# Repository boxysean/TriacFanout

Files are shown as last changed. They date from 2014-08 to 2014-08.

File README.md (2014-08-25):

Triac Fanout board for daisy-chainable 8x triac (lightbulb) outputs and Arduino library. So far tested for 8 channels.

[Video](http://instagram.com/p/sIGZ_VrQKr/?modal=true)

Written by Sean McIntyre.
MIT license, all text above must be included in any redistribution

Place the TriacFanout library folder in your <arduinosketchfolder>/libraries/ folder. You may need to create the libraries subfolder if its your first library. Restart the IDE

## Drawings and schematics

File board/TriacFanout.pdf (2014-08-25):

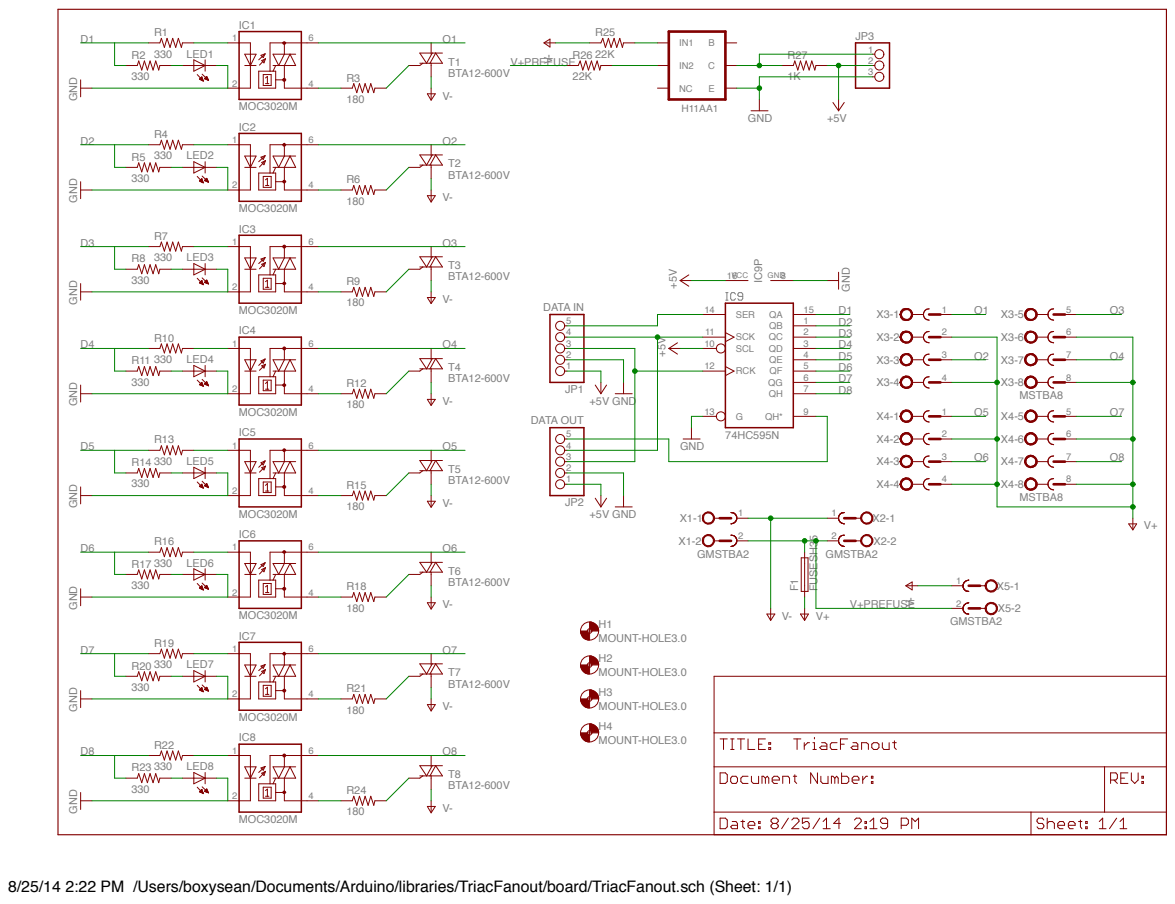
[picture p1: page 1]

8/25/14 2:22 PM /Users/boxysean/Documents/Arduino/libraries/TriacFanout/board/TriacFanout.sch (Sheet: 1/1)

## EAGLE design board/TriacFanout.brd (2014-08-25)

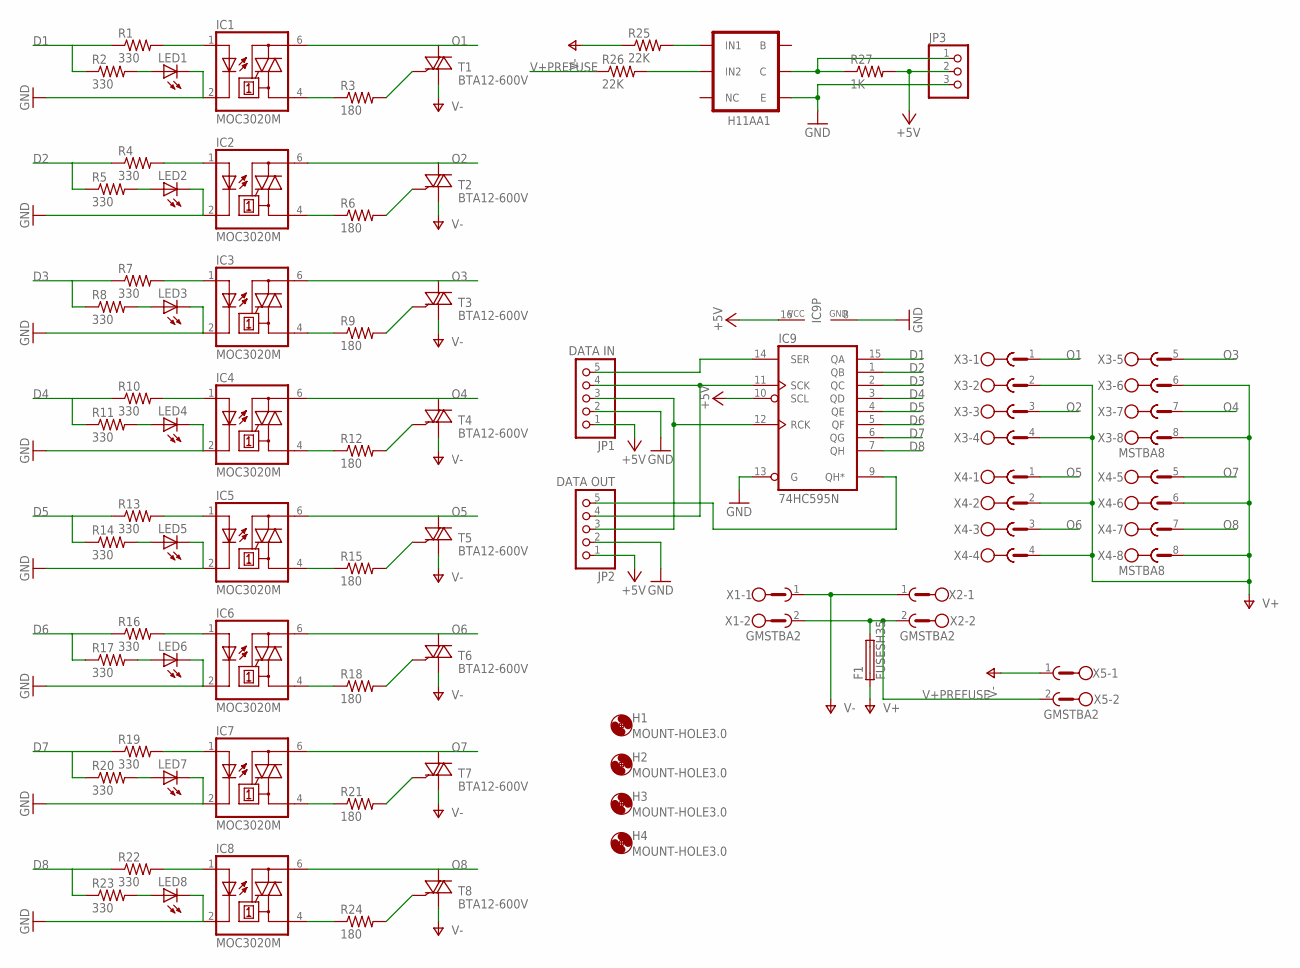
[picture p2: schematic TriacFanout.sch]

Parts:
F1: FUSESH35; SH25
H1, H2, H3, H4: MOUNT-HOLE3.0; 3,0
IC1, IC2, IC3, IC4, IC5, IC6, IC7, IC8: MOC3020M; DIL06
IC9: 74HC595N; DIL16
JP1: DATA IN; 1X05
JP2: DATA OUT; 1X05
JP3: PINHD-1X3; 1X03
LED1, LED2, LED3, LED4, LED5, LED6, LED7, LED8: LED5MM
R1, R2, R4, R5, R7, R8, R10, R11, R13, R14, R16, R17, R19, R20, R22, R23: 330; 0207/10
R3, R6, R9, R12, R15, R18, R21, R24: 180; 0207/10
R25, R26: 22K; 0411/12
R27: 1K; 0207/10
T1, T2, T3, T4, T5, T6, T7, T8: BTA12-600V; TO220V
U$1: H11AA1; DIL06
X1, X2, X5: GMSTBA2
X3, X4: MSTBA8

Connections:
+5V: IC9.10 (SCL), IC9.16 (VCC), JP1.1, JP2.1, JP3.2, R27.2
CLOCK: IC9.11 (SCK), JP1.4, JP2.4
D1: IC9.15 (QA), R1.1, R2.1
D2: IC9.1 (QB), R4.1, R5.1
D3: IC9.2 (QC), R7.1, R8.1
D4: IC9.3 (QD), R10.1, R11.1
D5: IC9.4 (QE), R13.1, R14.1
D6: IC9.5 (QF), R16.1, R17.1
D7: IC9.6 (QG), R19.1, R20.1
D8: IC9.7 (QH), R22.1, R23.1
DATA: IC9.14 (SER), JP1.5
GND: IC1.2 (C), IC2.2 (C), IC3.2 (C), IC4.2 (C), IC5.2 (C), IC6.2 (C), IC7.2 (C), IC8.2 (C), IC9.8 (GND), IC9.13 (G), JP1.2, JP2.2, JP3.3, LED1.K (C), LED2.K (C), LED3.K (C), LED4.K (C), LED5.K (C), LED6.K (C), LED7.K (C), LED8.K (C), U$1.4 (E)
LATCH: IC9.12 (RCK), JP1.3, JP2.3
unnamed: IC2.1 (A), R4.2
unnamed: LED2.A, R5.2
unnamed: IC2.4 (A1), R6.1
unnamed: R6.2, T2.3 (G)
unnamed: IC3.1 (A), R7.2
unnamed: LED3.A, R8.2
unnamed: IC3.4 (A1), R9.1
unnamed: R9.2, T3.3 (G)
unnamed: IC1.4 (A1), R3.1
unnamed: IC1.1 (A), R1.2
unnamed: R3.2, T1.3 (G)
unnamed: LED1.A, R2.2
unnamed: IC4.1 (A), R10.2
unnamed: LED4.A, R11.2
unnamed: IC4.4 (A1), R12.1
unnamed: R12.2, T4.3 (G)
unnamed: IC5.1 (A), R13.2
unnamed: LED5.A, R14.2
unnamed: IC5.4 (A1), R15.1
unnamed: R15.2, T5.3 (G)
unnamed: IC6.1 (A), R16.2
unnamed: LED6.A, R17.2
unnamed: IC6.4 (A1), R18.1
unnamed: R18.2, T6.3 (G)
unnamed: IC7.1 (A), R19.2
unnamed: LED7.A, R20.2
unnamed: IC7.4 (A1), R21.1
unnamed: R21.2, T7.3 (G)
unnamed: IC8.1 (A), R22.2
unnamed: LED8.A, R23.2
unnamed: IC8.4 (A1), R24.1
unnamed: R24.2, T8.3 (G)
unnamed: R25.2, U$1.1 (IN1)
unnamed: R26.2, U$1.2 (IN2)
O1: IC1.6 (A2), T1.2 (A2), X3.1
O2: IC2.6 (A2), T2.2 (A2), X3.3
O3: IC3.6 (A2), T3.2 (A2), X3.5
O4: IC4.6 (A2), T4.2 (A2), X3.7
O5: IC5.6 (A2), T5.2 (A2), X4.1
O6: IC6.6 (A2), T6.2 (A2), X4.3
O7: IC7.6 (A2), T7.2 (A2), X4.5
O8: IC8.6 (A2), T8.2 (A2), X4.7
OVERFLOW: IC9.9 (QH*), JP2.5
V+: F1.1, X3.2, X3.4, X3.6, X3.8, X4.2, X4.4, X4.6, X4.8
V+PREFUSE: F1.2, R26.1, X1.2, X2.2, X5.2
V-: R25.1, T1.1 (A1), T2.1 (A1), T3.1 (A1), T4.1 (A1), T5.1 (A1), T6.1 (A1), T7.1 (A1), T8.1 (A1), X1.1, X2.1, X5.1
ZEROCROSS: JP3.1, R27.1, U$1.5 (C)

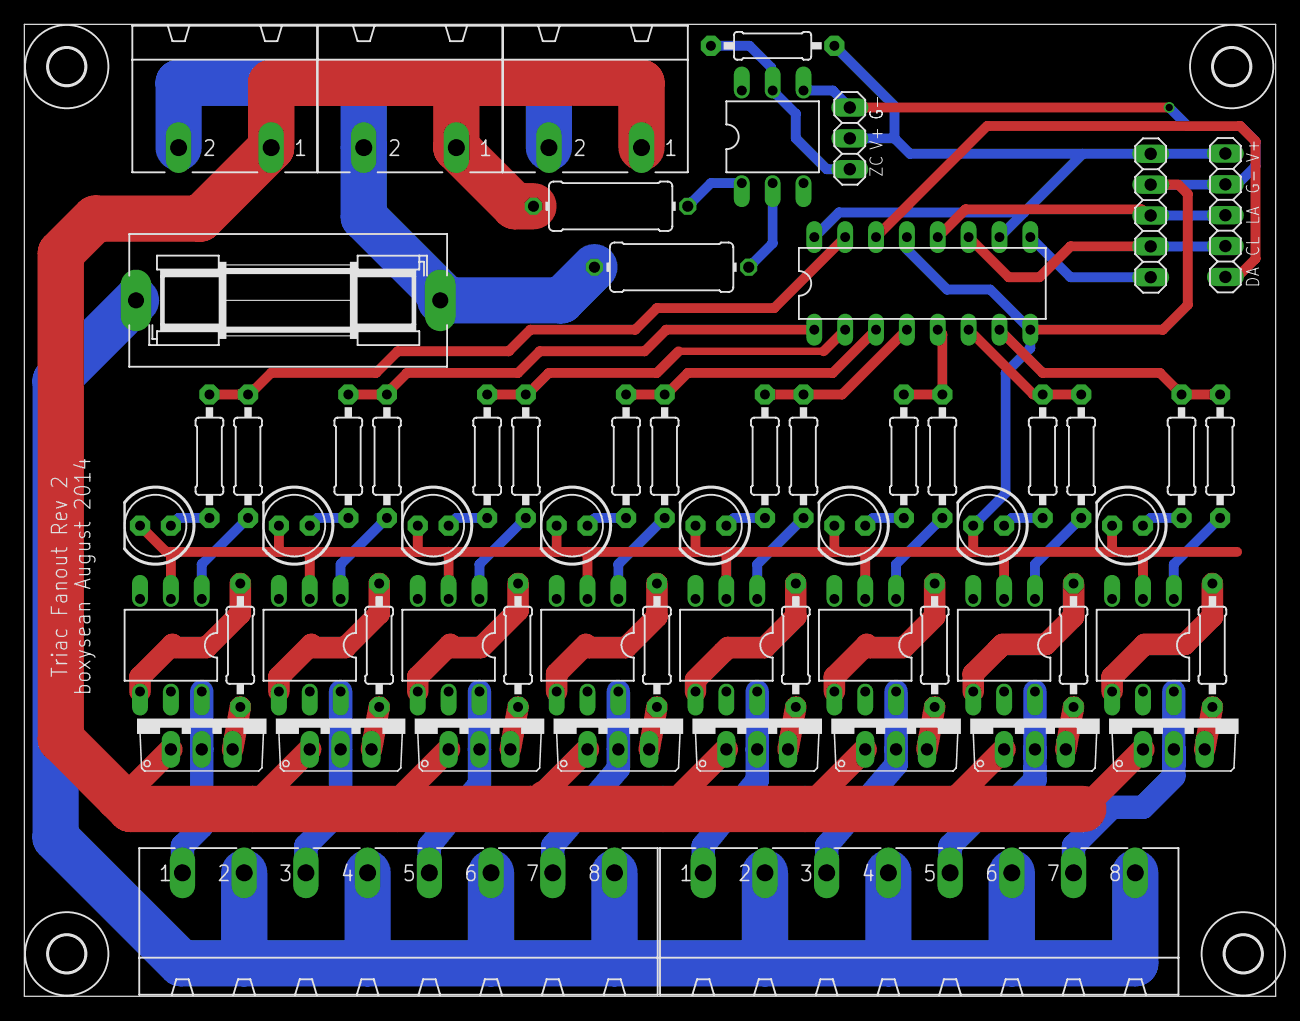
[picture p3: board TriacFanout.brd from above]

Board: 2 copper layers, 103.0 x 80.0 mm, 66 parts (0 on the bottom side), 60 nets.

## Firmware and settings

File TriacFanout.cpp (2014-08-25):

/*
  TriacFanout.cpp
  Created by Sean McIntyre, August 2014.
*/

#include "Arduino.h"
#include "TriacFanout.h"

// This is the delay-per-brightness step in microseconds.
// It is calculated based on the frequency of your voltage supply (50Hz or 60Hz)
// and the number of brightness steps you want. 
// 
// The only tricky part is that the chopper circuit chops the AC wave twice per
// cycle, once on the positive half and once at the negative half. This meeans
// the chopping happens at 120Hz for a 60Hz supply or 100Hz for a 50Hz supply. 

// To calculate freqStep you divide the length of one full half-wave of the power
// cycle (in microseconds) by the number of brightness steps. 
//
// (1000000 uS / 120 Hz) / 128 brightness steps = 65 uS / brightness step
//
// 1000000 us / 120 Hz = 8333 uS, length of one half-wave.
//
// Further modified to be 32 brightness steps (4 x 65 = 260), seems to give better results for flickering
int TriacFanout::freqStep = 260;



TriacFanout::TriacFanout() {
}

void TriacFanout::init(int numUnits = 1, int latchPin = 9) {
  if (numUnits < 1) {
    numUnits = 1;
  }

  this->numUnits = numUnits;
  this->latchPin = latchPin;

  Timer1.initialize(this->freqStep);                      // Initialize TimerOne library for the freq we need
  SPI.begin();

  pinMode(this->latchPin, OUTPUT);

  // pinMode(11, OUTPUT);
  // pinMode(13, OUTPUT);
}

void TriacFanout::setBrightness(int idx, int level) {
  brightness[idx] = level;
}

void TriacFanout::_zcDetect() {
  noInterrupts();

  this->zeroCross = true;
  this->stepCounter = 0;
  this->state = 0;

  this->update(this->state);

  interrupts();
}

// Turn on the TRIAC at the appropriate time
void TriacFanout::_dimCheck() {       
  noInterrupts();

  if (this->zeroCross) {
    bool updateNow = false;

    for (int i = 0; i < 8; i++) {
      if (this->stepCounter >= brightness[i]) {
        this->state |= (1 << i);
        updateNow = true;
      }
    }

    if (updateNow) {
      this->update(this->state);
    }

    this->stepCounter++;
  }

  interrupts();
}         

void TriacFanout::update(int newState) {
  SPI.transfer(newState);
  // shiftOut(11, 13, MSBFIRST, this->state);
  digitalWrite(this->latchPin, HIGH);
  digitalWrite(this->latchPin, LOW);
} 
